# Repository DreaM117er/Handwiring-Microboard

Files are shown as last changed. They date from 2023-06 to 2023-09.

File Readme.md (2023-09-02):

# Handwiring Microboard 手拉線拓展板

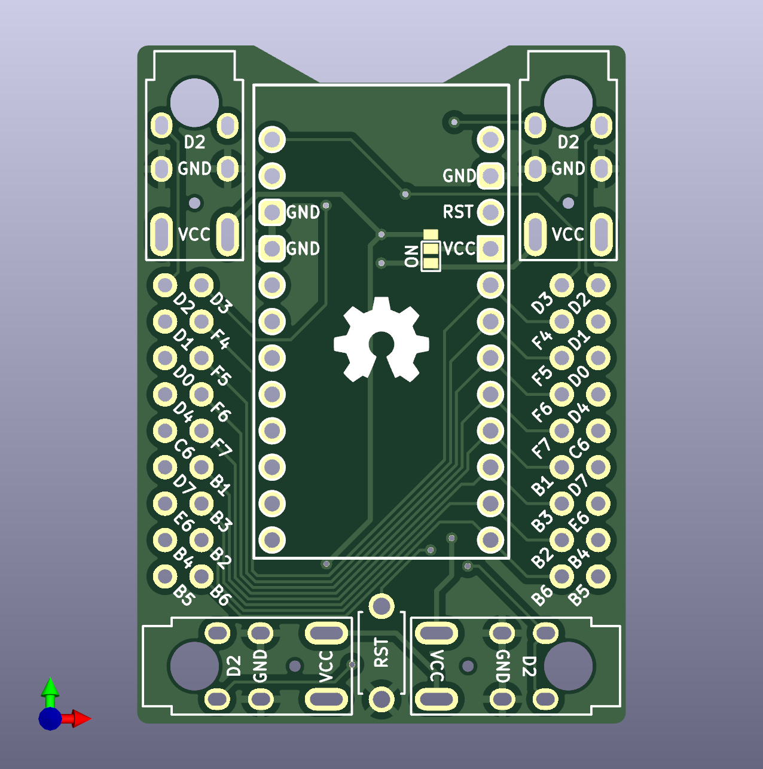
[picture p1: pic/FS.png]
Front side
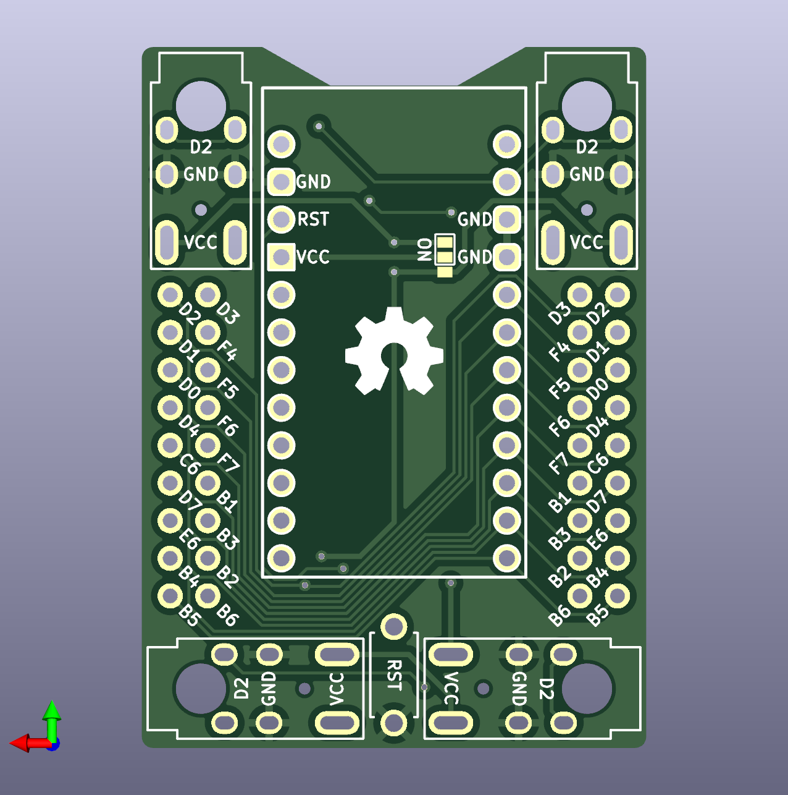
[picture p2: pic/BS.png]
Back side
|||
|--|--|
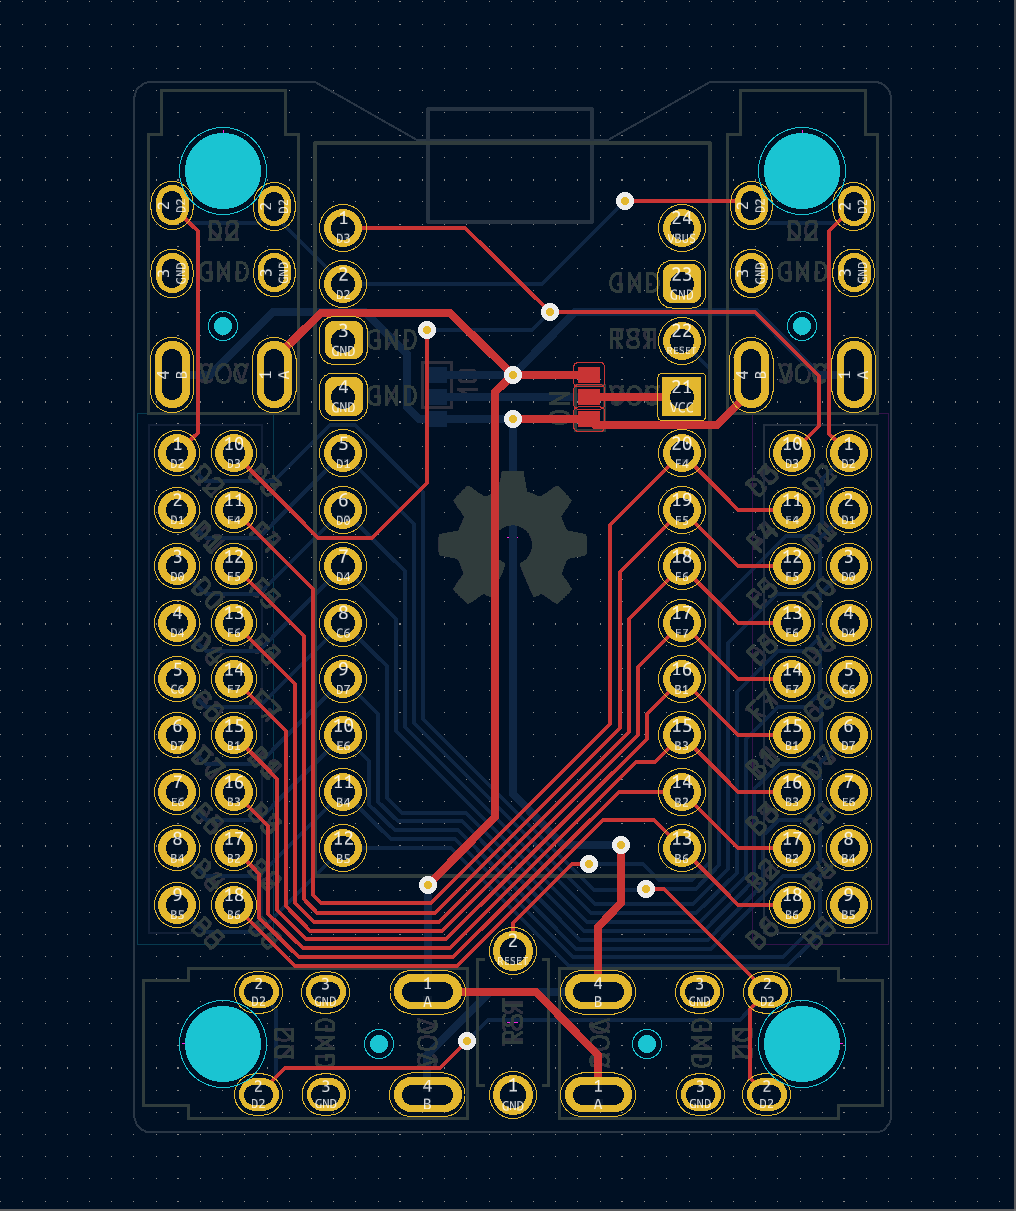
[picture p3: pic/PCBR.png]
PCBR
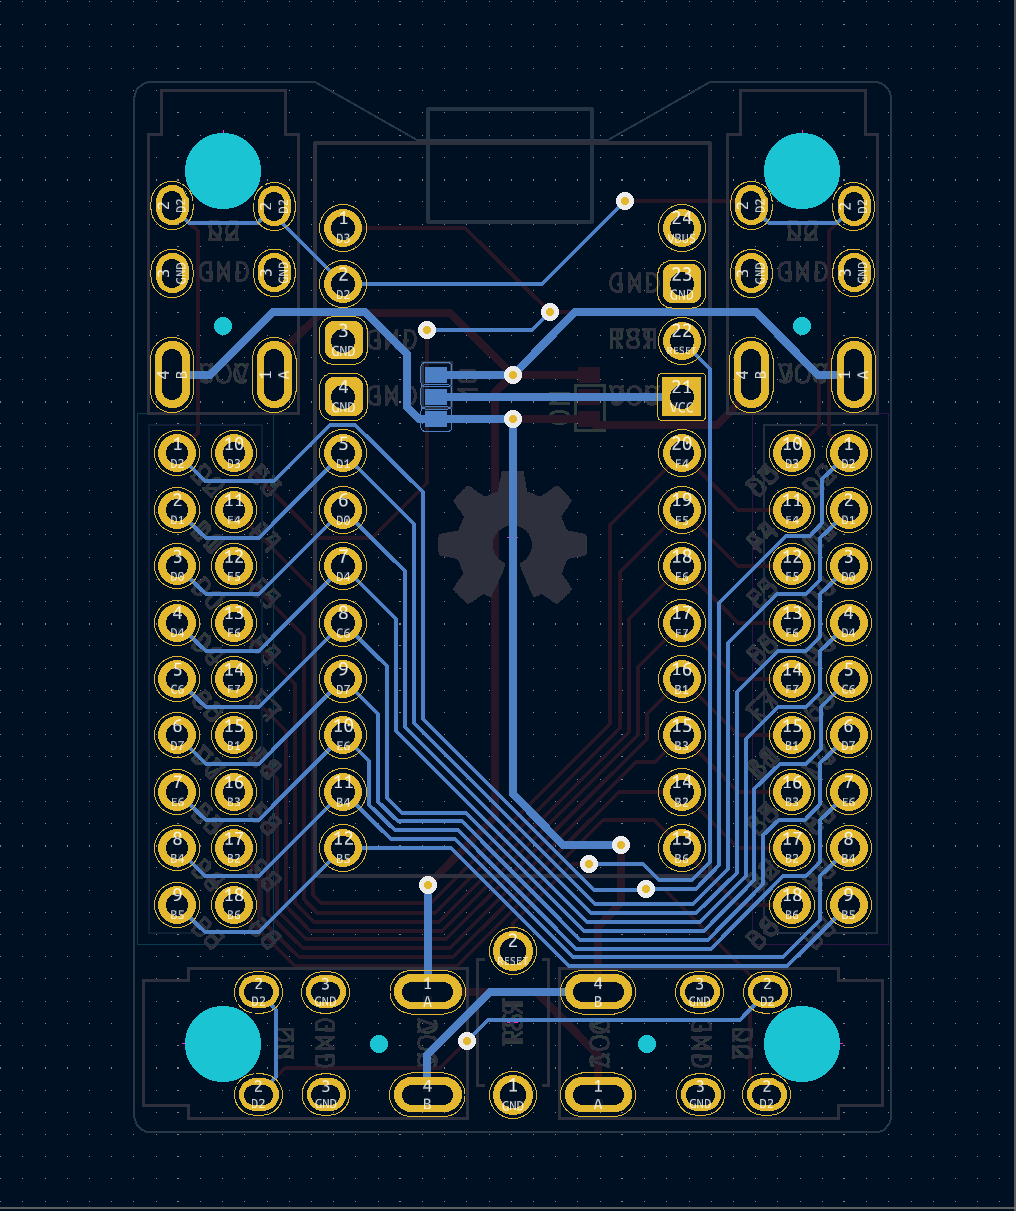
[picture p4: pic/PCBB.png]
PCBB
||||

## 詳細說明

在開源鍵盤的世界裡，Pro Micro、Elite-C等是最為常用的開發板，搭載客製化鍵盤很常見的ATMega32U4晶片，其腳位都為12+12 pin的設計。然而開發板本身是不帶螺絲孔位的，因此大部分的鍵盤開發者會將Pro Micro或Elite-C的footprint直接設計在鍵盤的PCB上，再對照韌體使用的Pin腳，連結鍵盤所需的矩陣及元件。

而手拉線拓展板就是為了解決這個問題而設計的，特色如下：

- 支援`正反面`MCU安裝。
- 集中MCU可編程的`18個pin腳`於左右兩側做對稱處理，可左右翻轉做安裝。
- 支援TRRS座`雙面安裝`，可安裝在`4個角落`位置、4個方向。
- 角落有4個`ø3.4mm`的螺絲孔位，可通過`M2`規格的`黃銅銅柱`。

## 使用方式

### A、使用材料

|零件名|數量|備註|
|--|--|--|
|電路板（`PCB`）|1片、2片|一體式、分離式|
|`2pin` 輕觸開關|1個||
|`MCU`|1個、2個|分離式鍵盤需用到2片|
|`TRRS座`|2個|分離式鍵盤用|
|單排排針|`9pin`、`12pin`||
|公母圓排針|`9pin`、`12pin`|推薦|

### B、安裝方式

#### a、一體式

- 首先準備好`PCB`、`MCU`、`2pin輕觸開關`。

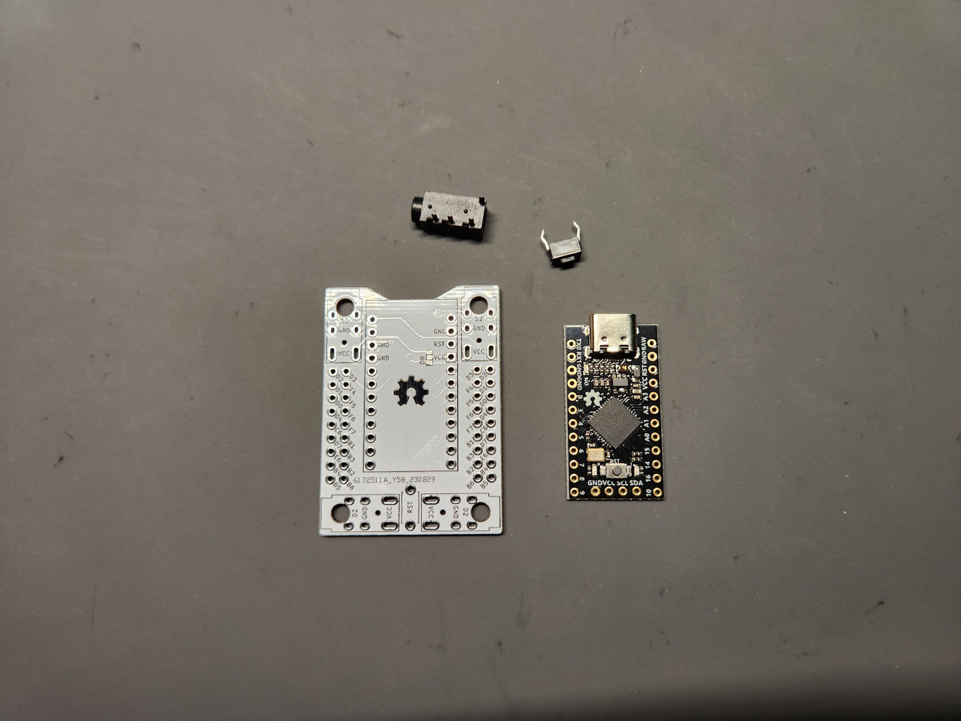
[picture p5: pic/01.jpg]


- 接著對好MCU上的`腳位`進行焊接安裝。

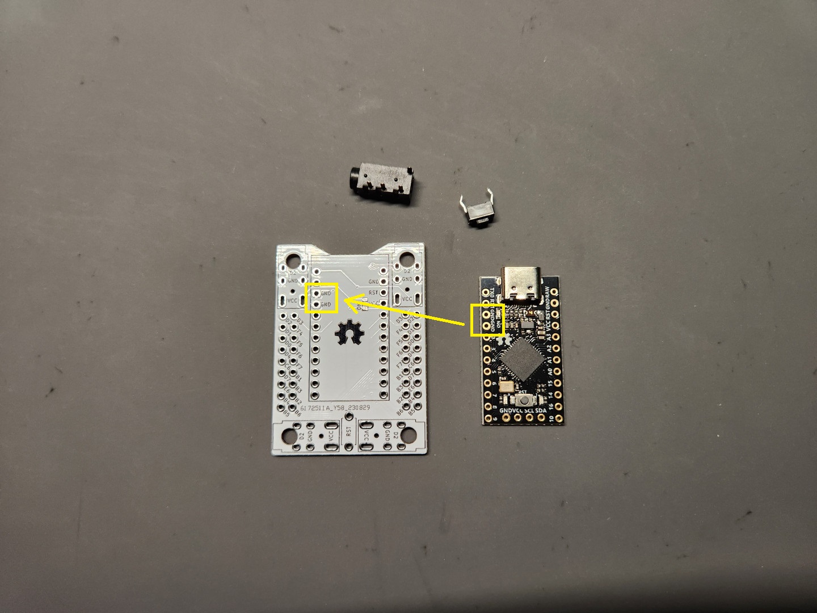
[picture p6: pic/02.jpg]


> **Note**
>
> MCU晶片朝下、朝上都可以安裝在手拉線拓展板上，對好板子上及MCU上的腳位即可。

- 這裡使用`公母圓排針`進行示範安裝。將公圓排針準備好，切正確的大小安裝到MCU上。

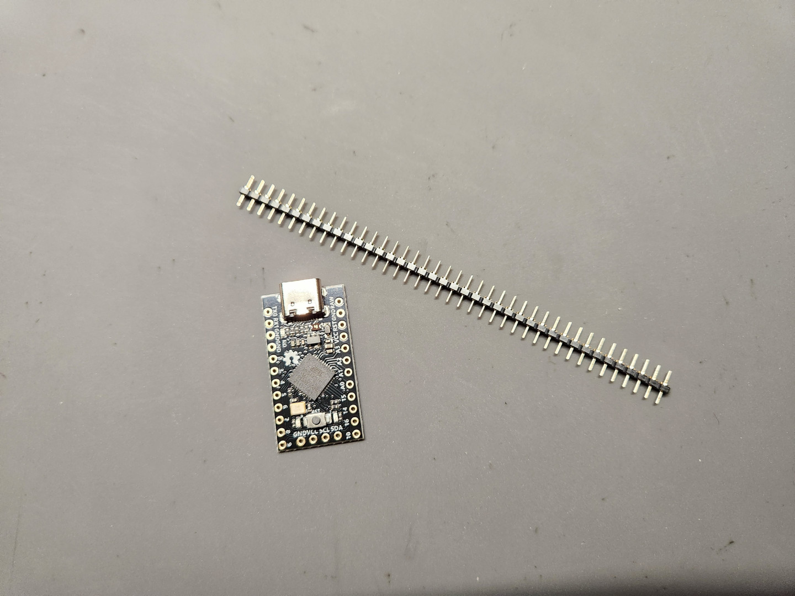
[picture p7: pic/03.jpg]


- 接著將MCU上的排針焊接完成。

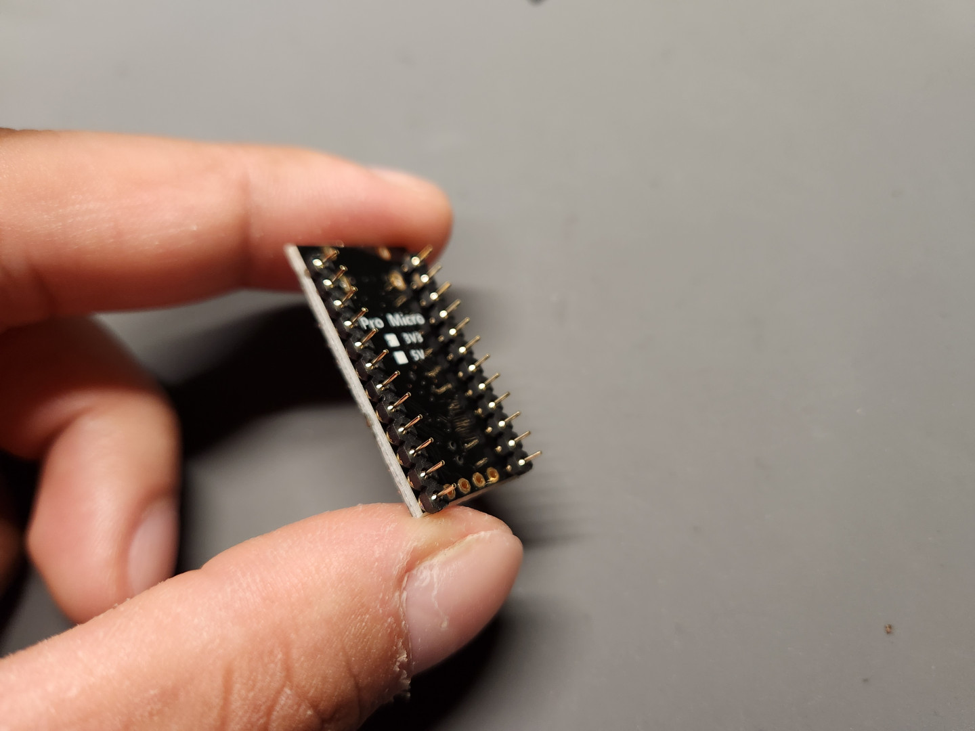
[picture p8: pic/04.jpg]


- 再來將`母排針座`安裝到拓展板上。

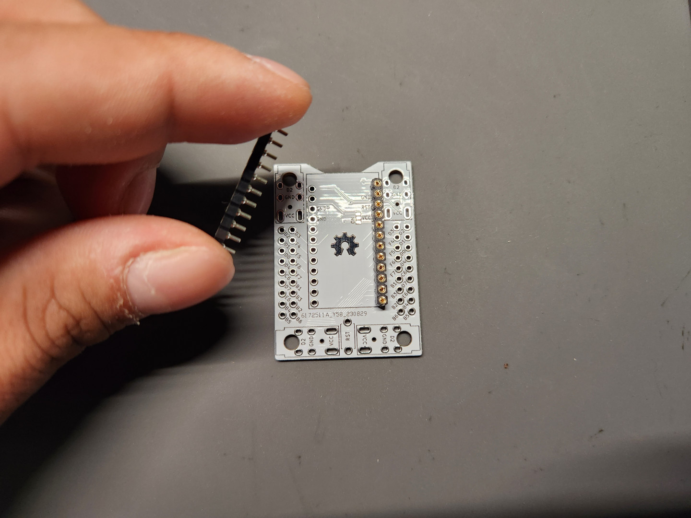
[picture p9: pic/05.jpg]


- 接著從背面焊接固定`母排針座`。

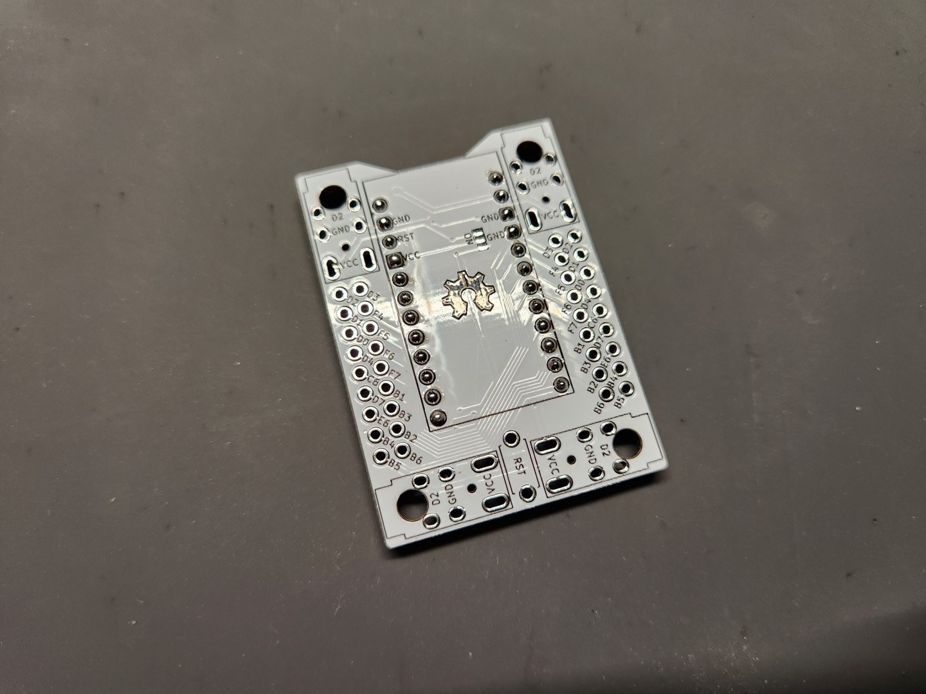
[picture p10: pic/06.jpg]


- 再將MCU安裝到拓展板上。

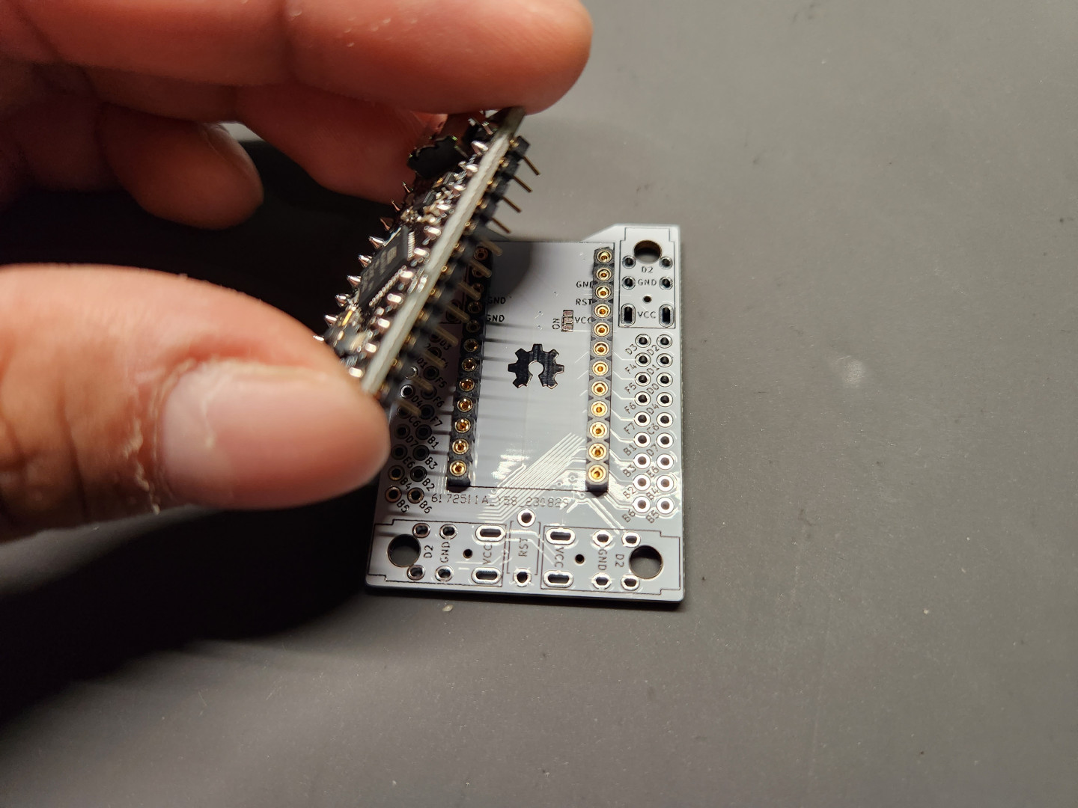
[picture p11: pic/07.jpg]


- 接著將`2pin輕觸`開關安裝上去焊接固定。

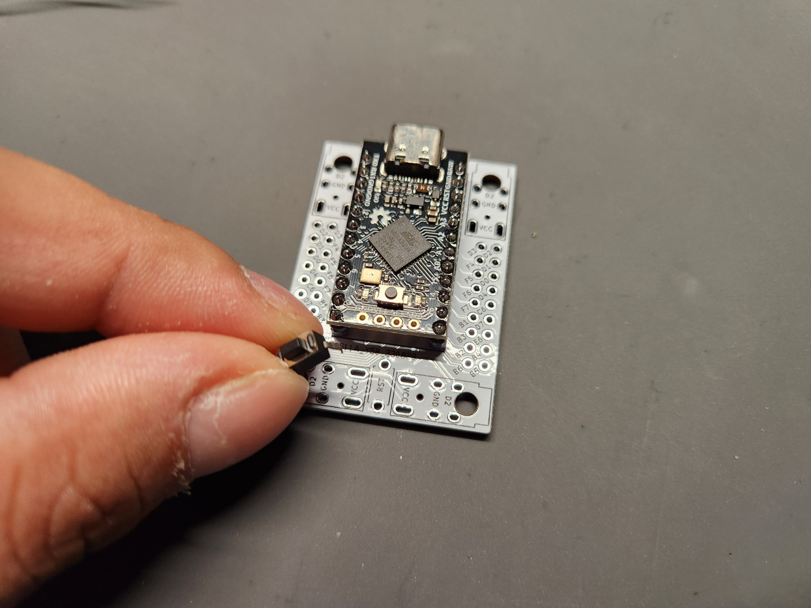
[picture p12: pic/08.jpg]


- 完成後會是這樣的感覺。

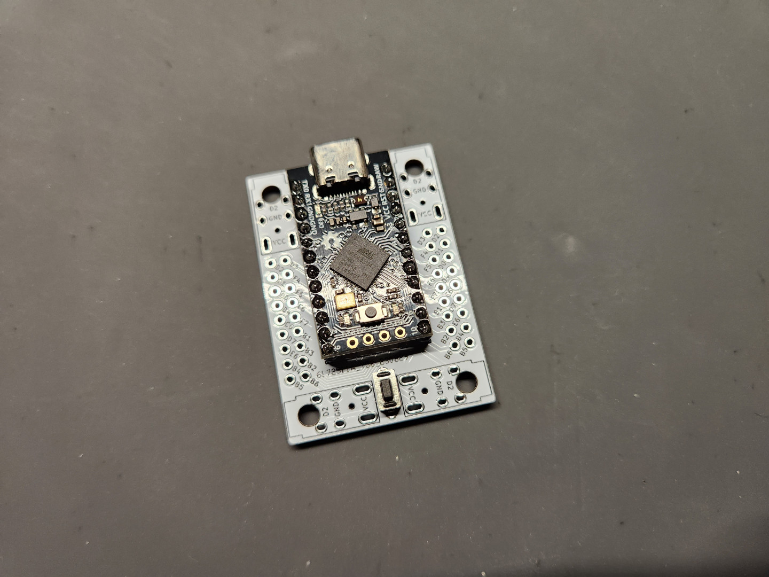
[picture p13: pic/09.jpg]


> **Note**
>
> 如果你的鍵盤是一體式設計，接著將韌體燒錄進MCU後，就可以使用了。

#### b、分離式

> **Note**
>
> 如果你的鍵盤設計屬分離式，那麼請繼續看下去。

- 接著將已經焊接好MCU的手拉線拓展板跟`TRRS座`準備好。

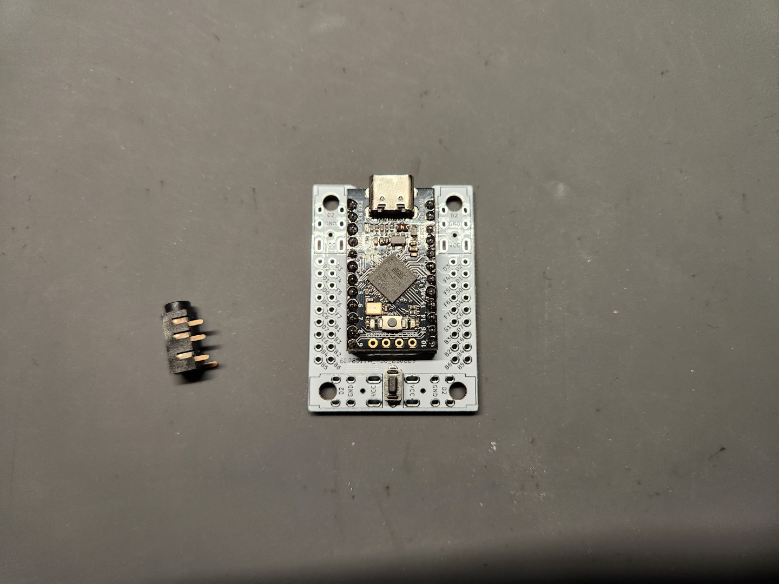
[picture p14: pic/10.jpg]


> **Warning**
>
> TRRS座有4個位置可以安裝選擇，請選一個自己想要的位置安裝。

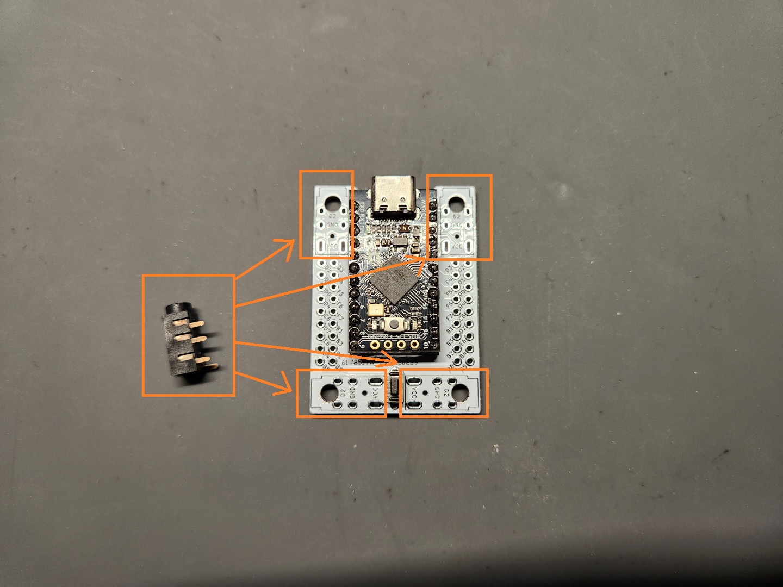
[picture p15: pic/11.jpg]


- 接著將`TRRS座`焊接固定好。

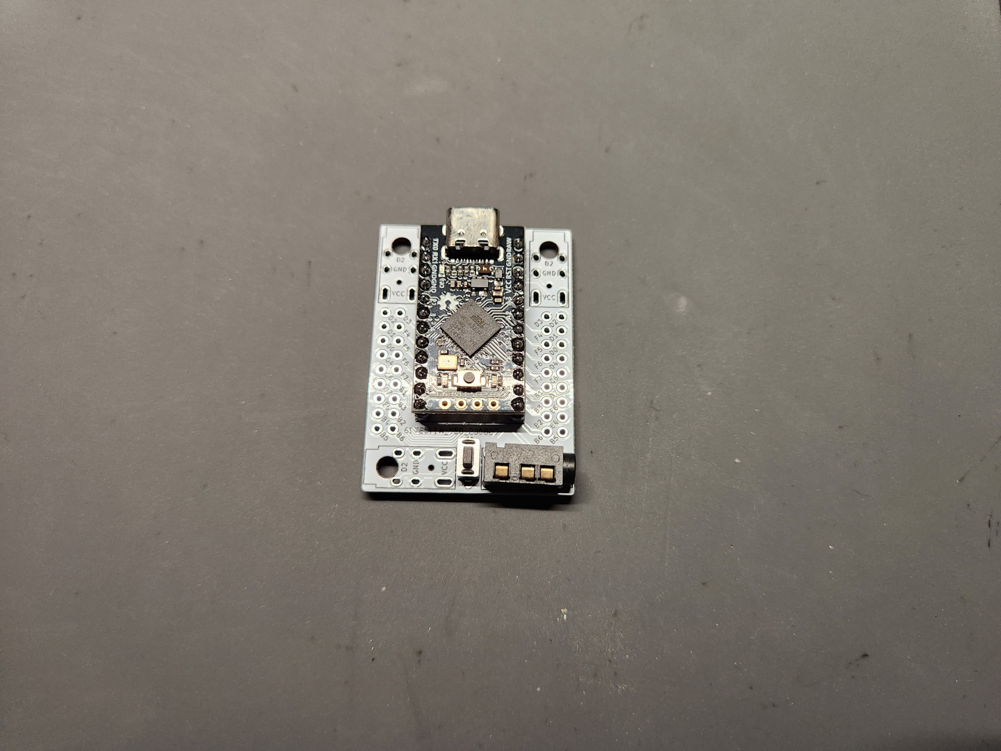
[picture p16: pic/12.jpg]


- 焊接好之後翻至`背面`，接著將背面的`跳線ON`的部分焊接起來。

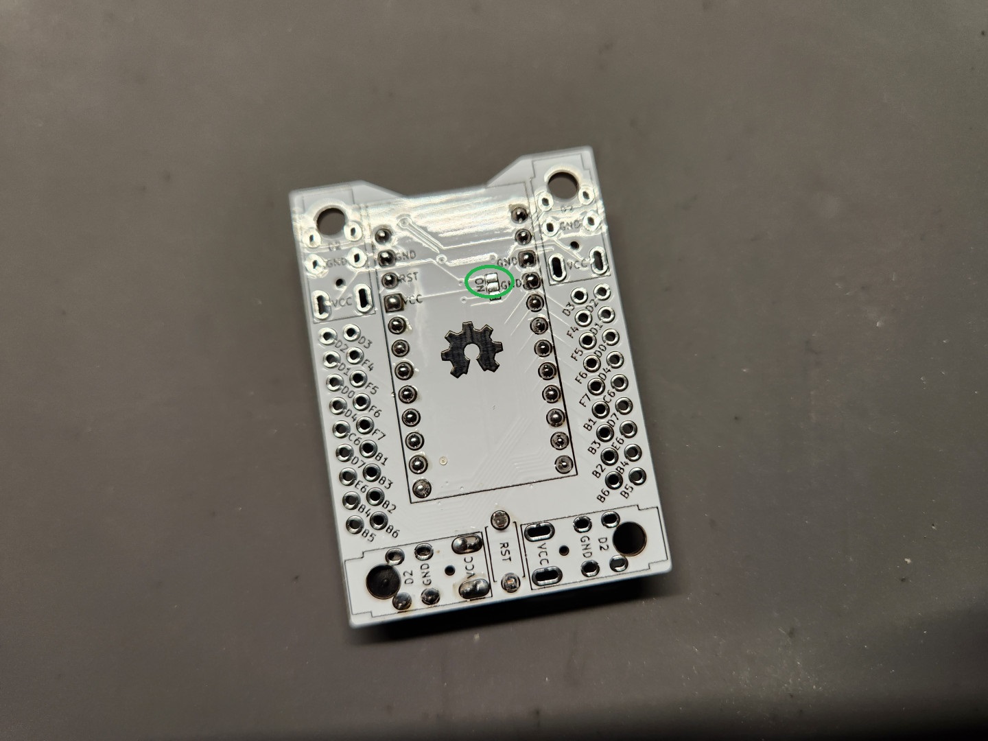
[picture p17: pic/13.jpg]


- 跳線焊接好後會是這樣。

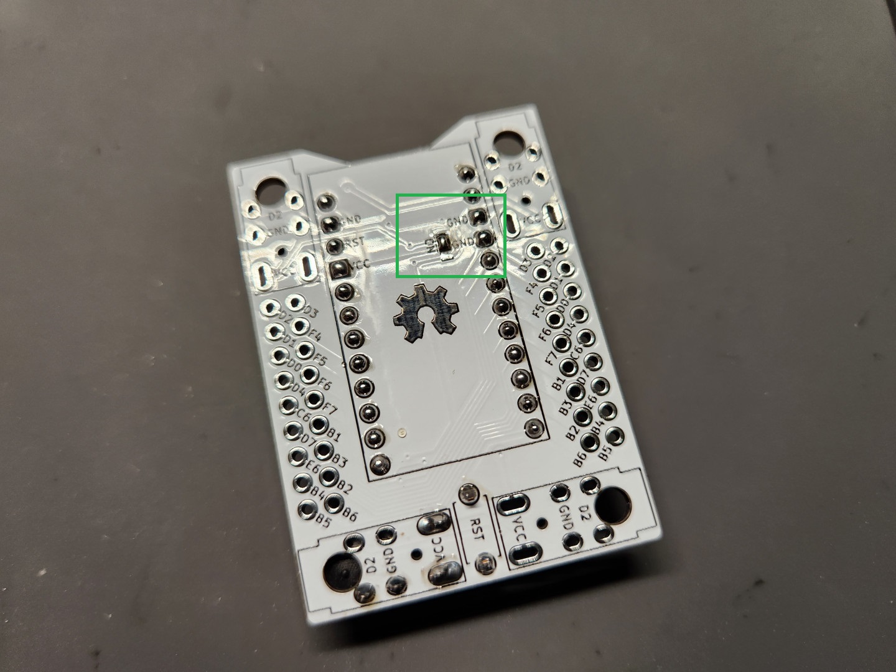
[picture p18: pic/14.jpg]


> **Warning**
>
> 跳線連接的方式會依照MCU朝上、朝下安裝方式的不同而有差異，務必留意。

- 接著準備好左右邊鍵盤的手拉線拓展板，將韌體燒錄到左右邊，再接上`TRS`/`TRRS線`測試鍵盤即可使用。

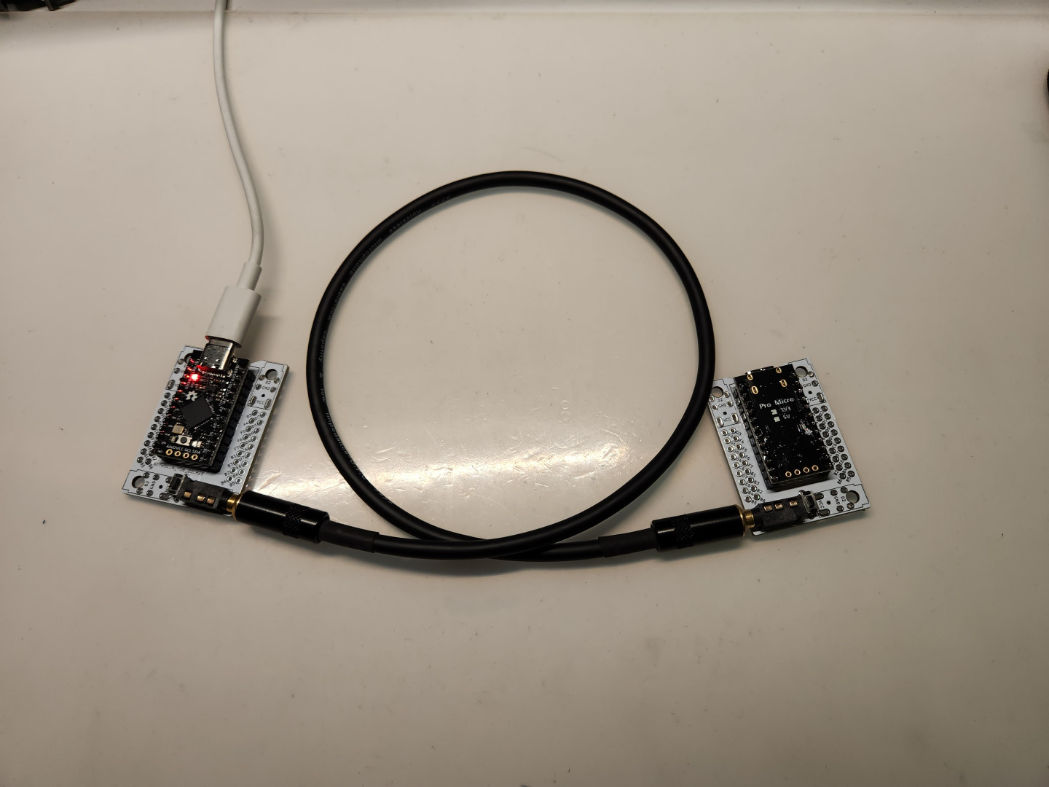
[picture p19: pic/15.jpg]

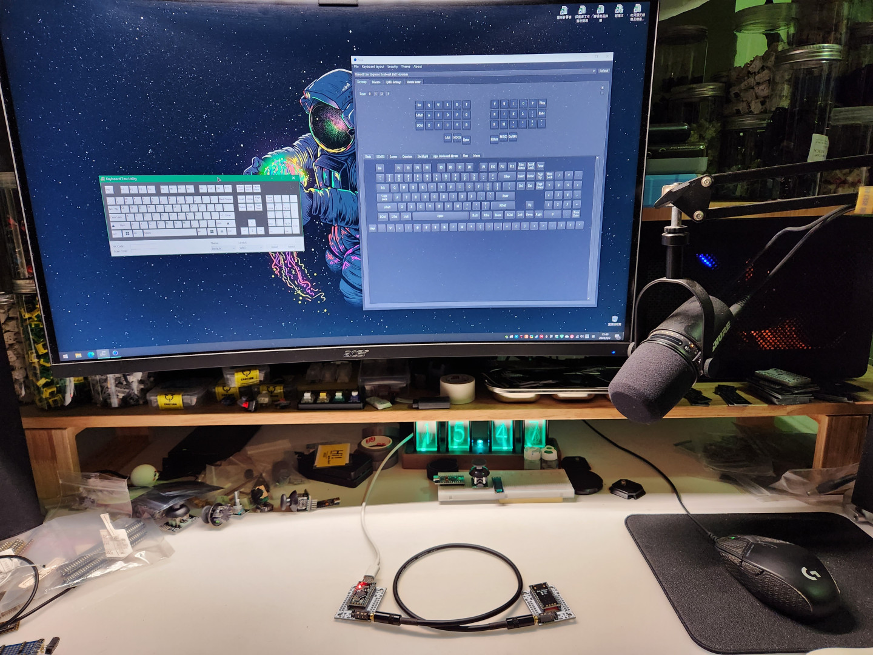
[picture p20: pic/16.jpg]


## 注意事項

> **Warning**
>
> `MCU`、`TRRS座`、`2pin輕觸開關`務必安裝在`同一側`，以免拓展板失靈。

> **Note**
>
> 拓展板支援`Pro Micro`、`Elite-C`等`12+12 pin`的MCU。

> **Warning**
>
> 如使用`Micro Pico`等`RP2040`等MCU，請依照下表進行`IO pin`的轉換。（以`Sea-Picro`為例）

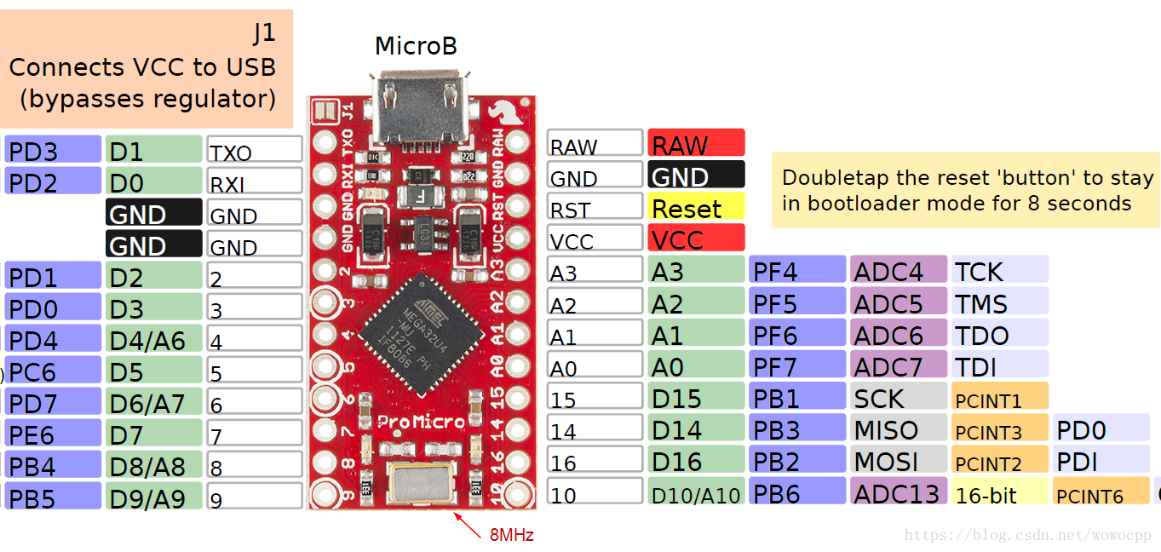
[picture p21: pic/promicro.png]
Pro Micro
|Pro Micro||
|--|--|
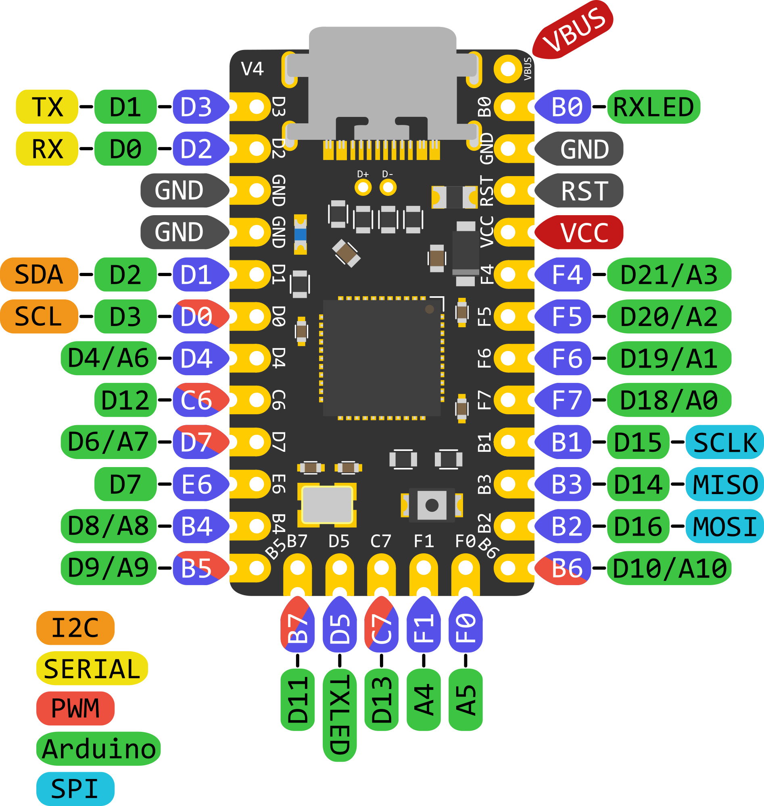
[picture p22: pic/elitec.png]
Elite-C
|Elite-C||
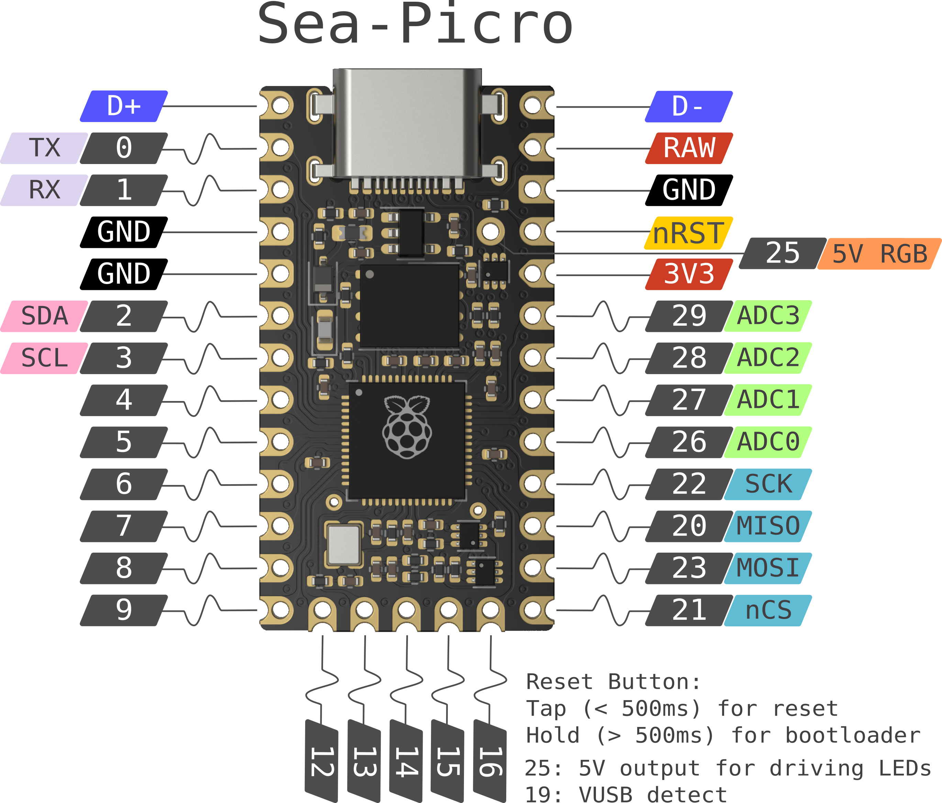
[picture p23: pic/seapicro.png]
Sea-Picro
|Sea-Picro||

### IO Pin對照表：

|**Pro Micro、Elite-C左側**|**Pico左側**|**Pro Micro、Elite-C右側**|**Pico右側**|
|--|--|--|--|
|-|`D+`|`VBUS`|`D-`|
|`D3`|`GP0`|`B0`|`RAW`|
|`D2`|`GP1`|`GND`|`GND`|
|`GND`|`GND`|`RST`|`RST`|
|`GND`|`GND`|`VCC`|`3V3`|
|`D1`|`GP2`|`F4`|`GP29`|
|`D0`|`GP3`|`F5`|`GP28`|
|`D4`|`GP4`|`F6`|`GP27`|
|`C6`|`GP5`|`F7`|`GP26`|
|`D7`|`GP6`|`B1`|`GP22`|
|`E6`|`GP7`|`B3`|`GP20`|
|`B4`|`GP8`|`B2`|`GP23`|
|`B5`|`GP9`|`B6`|`GP21`|
|**Elite-C下方**|**Pico下方**|--|--|
|`B7`|`GP12`|--|--|
|`D5`|`GP13`|--|--|
|`C7`|`GP14`|--|--|
|`F1`|`GP15`|--|--|
|`F0`|`GP16`|--|--|

> **Note**
>
> 如鍵盤要將手拉線拓展板設計到鍵盤內，請使用`step檔`進行3D模型的設計。

拓展板規格如下：
- 螺絲孔大小: `ø3.4 mm.`
- 拓展板大小: `34.084 x 47.310 mm`
- 螺絲孔間距: `26.08 mm`, `39.307 mm`

> **Warning**
>
> `TRRS座`預設使用`D2/GP1`進行左右邊鍵盤的資料傳輸，請務必留意。

```
#define SOFT_SERIAL_PIN [D2/GP1]
```

## 參考資料及使用說明

- JLCPCB。
- KiCAD version `7.05`。
- Fusion360。
- `Pro Micro`、`Elite-C`、`Micro Pico`、`Sea Picro`。

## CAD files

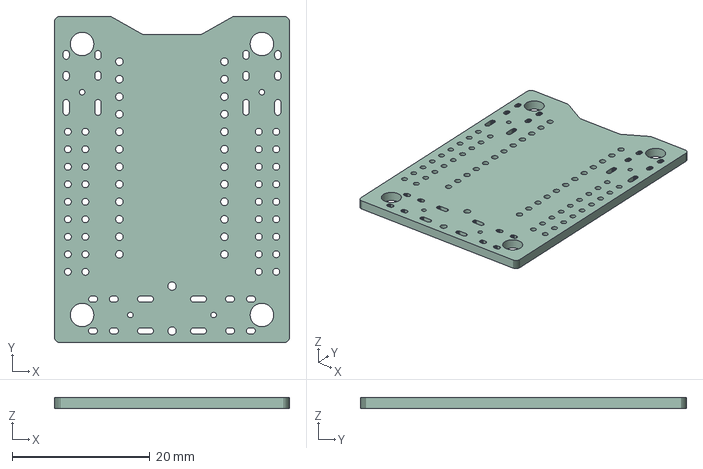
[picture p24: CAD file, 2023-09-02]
step/handwire microboard.step
34.1 x 47.3 x 1.60 mm

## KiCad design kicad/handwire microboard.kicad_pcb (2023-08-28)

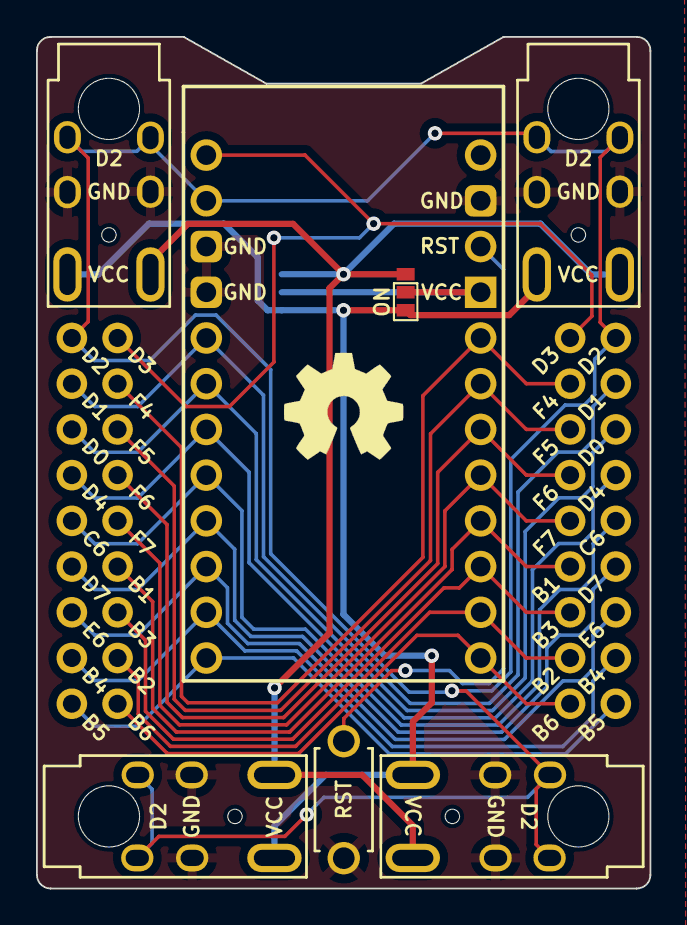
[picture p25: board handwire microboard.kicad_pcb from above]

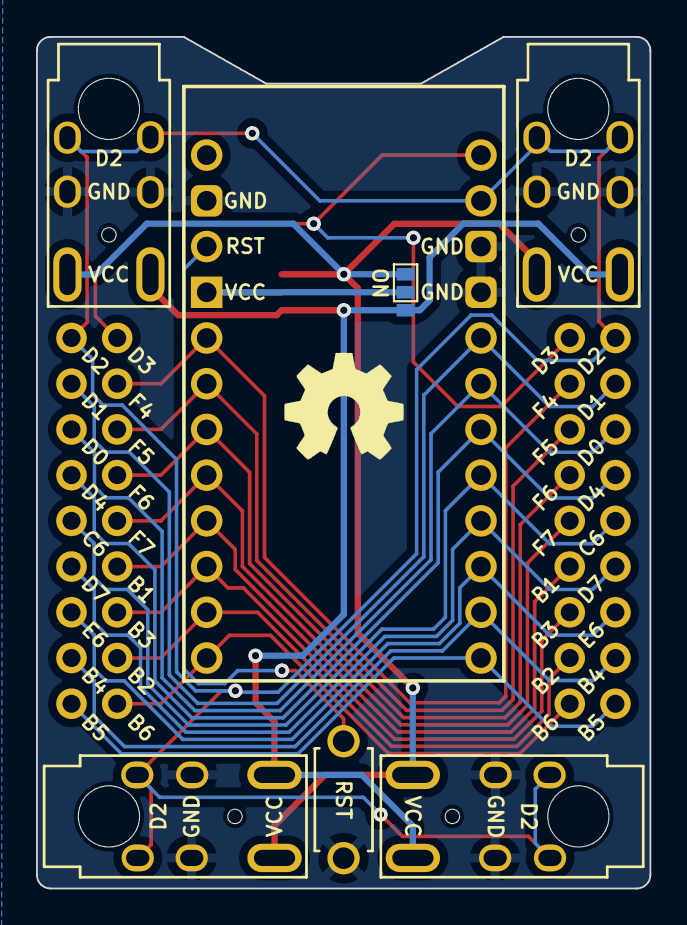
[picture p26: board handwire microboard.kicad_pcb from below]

Board: 2 copper layers, 34.1 x 47.3 mm, 10 parts (2 on the bottom side), 23 nets.

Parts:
J1, J2: ProMicro18pin; PinHeader_2x09_P2.54mm_Vertical_Rside
ON: Jumper_Fside; SolderJumper-3_P1.3mm_Open_Pad0.7.x1.0mm_NumberLabels
ON#2: Jumper_Bside; SolderJumper-3_P1.3mm_Open_Pad0.7.x1.0mm_NumberLabels
SW1: SW_Push; ResetSW_1side
T1, T2, T3, T4: AudioJack4; TRRS-PJ-320A, dual side
U1: ProMicro

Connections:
A: ON.1 (A), ON#2.1 (A), T1.1 (T/VCC), T2.1 (T/VCC), T3.1 (T/VCC), T4.1 (T/VCC)
B: ON.3 (B), ON#2.3 (B), T1.4 (S/No), T2.4 (S/No), T3.4 (S/No), T4.4 (S/No)
B1: J1.15, J2.15, U1.16 (22/PB1)
B2: J1.17, J2.17, U1.14 (23/PB2)
B3: J1.16, J2.16, U1.15 (20/PB3)
B4: J1.8, J2.8, U1.11 (8/PB4)
B5: J1.9, J2.9, U1.12 (9/PB5)
B6: J1.18, J2.18, U1.13 (21/PB6)
C6: J1.5, J2.5, U1.8 (5/PC6)
D0: J1.3, J2.3, U1.6 (3/PD0)
D1: J1.2, J2.2, U1.5 (2/PD1)
D2: J1.1, J2.1, T1.2 (R/SNL), T2.2 (R/SNL), T3.2 (R/SNL), T4.2 (R/SNL), U1.2 (1/PD2)
D3: J1.10, J2.10, U1.1 (0/PD3)
D4: J1.4, J2.4, U1.7 (4/PD4)
D7: J1.6, J2.6, U1.9 (6/PD7)
E6: J1.7, J2.7, U1.10 (7/PE6)
F4: J1.11, J2.11, U1.20 (29/PF4)
F5: J1.12, J2.12, U1.19 (28/PF5)
F6: J1.13, J2.13, U1.18 (27/PF6)
F7: J1.14, J2.14, U1.17 (26/PF7)
GND: SW1.1, T1.3 (R/GND), T2.3 (R/GND), T3.3 (R/GND), T4.3 (R/GND), U1.3 (GND), U1.4 (GND), U1.23 (GND)
RESET: SW1.2, U1.22 (RST)
VCC: ON.2 (C), ON#2.2 (C), U1.21 (VCC)

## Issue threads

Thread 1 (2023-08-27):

Don't use TRRS jack, it isn't supported TRS cable.

DreaM117er, 2023-08-27:
In Schematic Editor from KiCAD, I found TRRS jack used S and T pin to link VCC, it would cause TRS cable doesn't work, TRRS cable dose.

About Explorer Keyboard Mountian, if you don't want to build split version, it is fine to use old HWMB file.

DreaM117er, 2023-08-27:
now I changed schematic and re-design this PCB, I will make once new PCB to test, this issue will be close after testing.

DreaM117er, 2023-09-02:
I got new board from JLCPCB, then it passed all test about TRS and TRRS cable plug in the jack. It worked nicely, good.
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

Closed 2023-09-02.

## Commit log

2023-06-14 update files and readme.md
    [handwire microboard-B_Cu.gbl, handwire microboard-B_Mask.gbs, handwire microboard-B_Paste.gbp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]
2023-06-14 fixed waring on gbr files
    [handwire microboard-B_Cu.gbl, handwire microboard-B_Mask.gbs, handwire microboard-B_Paste.gbp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]
2023-06-14 renew readme.md
    [handwire microboard-B_Cu.gbl, handwire microboard-B_Mask.gbs, handwire microboard-B_Paste.gbp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]
2023-06-15 fix pcb files
    [handwire microboard-B_Cu.gbl, handwire microboard-B_Mask.gbs, handwire microboard-B_Paste.gbp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]
2023-06-20 re-design for board
    [handwire microboard-B_Cu.gbl, handwire microboard-B_Mask.gbs, handwire microboard-B_Paste.gbp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]
2023-06-20 update new garber files
    [handwire microboard-B_Cu.gbl, handwire microboard-B_Mask.gbs, handwire microboard-B_Paste.gbp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]
2023-06-20 update step file
    [handwire microboard.step]
2023-06-21 fix 80% keyboard pin used
    [handwire microboard-B_Cu.gbl, handwire microboard-B_Mask.gbs, handwire microboard-B_Paste.gbp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]
2023-06-22 update gerber files
    [handwire microboard-B_Cu.gbl, handwire microboard-B_Mask.gbs, handwire microboard-B_Paste.gbp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]
2023-07-20 re-design for the board
    [handwire microboard-B_Cu.gbl, handwire microboard-B_Mask.gbs, handwire microboard-B_Paste.gbp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]
2023-07-20 update new files
    [handwire microboard-B_Cu.gbl, handwire microboard-B_Mask.gbs, handwire microboard-B_Paste.gbp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]
2023-08-14 update pcb files
    [handwire microboard-B_Cu.gbl, handwire microboard-B_Mask.gbs, handwire microboard-B_Paste.gbp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]
2023-08-19 update new pcb
    [handwire microboard-B_Cu.gbl, handwire microboard-B_Mask.gbs, handwire microboard-B_Paste.gbp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]
2023-08-27 fixed issue and update files
    [handwire microboard-B_Cu.gbl, handwire microboard-B_Mask.gbs, handwire microboard-B_Paste.gbp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]
2023-08-27 update files
    [handwire microboard-B_Cu.gbl, handwire microboard-B_Mask.gbs, handwire microboard-B_Paste.gbp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]
2023-08-28 update new design file
    [handwire microboard-B_Cu.gbl, handwire microboard-B_Mask.gbs, handwire microboard-B_Paste.gbp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]
2023-08-28 new design
    [handwire microboard-B_Cu.gbl, handwire microboard-B_Mask.gbs, handwire microboard-B_Paste.gbp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]
2023-08-28 update new design
    [handwire microboard-B_Cu.gbl, handwire microboard-B_Mask.gbs, handwire microboard-B_Paste.gbp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]
2023-08-28 fixed one track
    [handwire microboard-B_Cu.gbl, handwire microboard-B_Mask.gbs, handwire microboard-B_Paste.gbp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]
2023-09-02 Update handwire microboard.step
    [handwire microboard.step]
